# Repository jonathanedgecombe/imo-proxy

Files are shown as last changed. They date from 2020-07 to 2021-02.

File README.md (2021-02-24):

A hardware USB/HID proxy designed for the IntelliMouse Optical 1.1A. Overclocks to 1000Hz polling rate and adds switch debouncing.

Other mice could be supported by modifying the report descriptors & report parsing, or implementing a complete report descriptor parser.

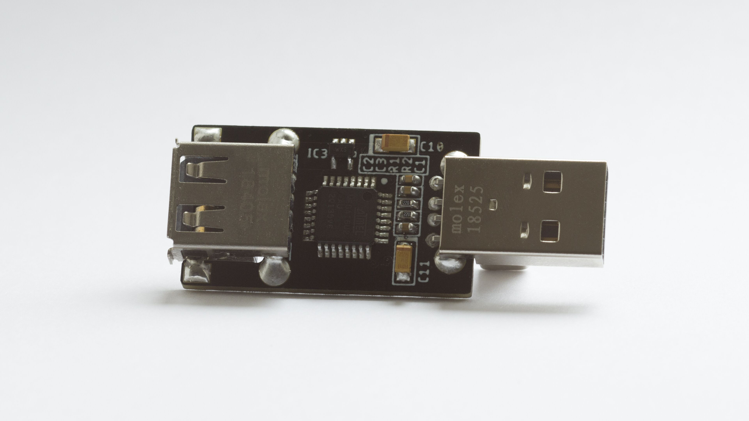
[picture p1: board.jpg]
Board photo


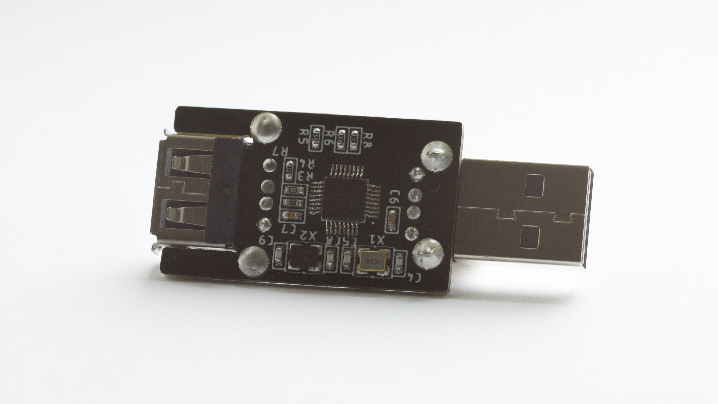
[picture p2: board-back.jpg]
Board photo back


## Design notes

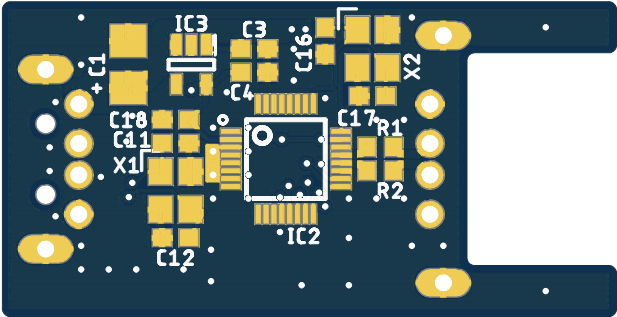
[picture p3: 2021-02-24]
render-back.png

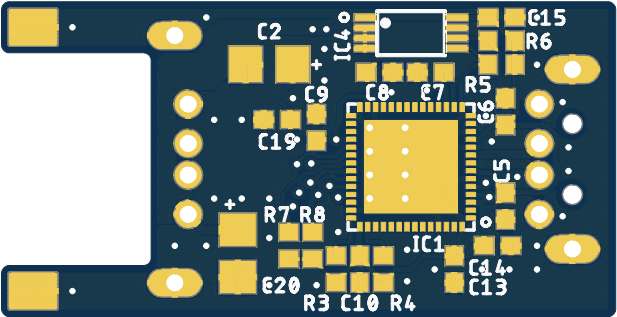
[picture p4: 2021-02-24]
render.png

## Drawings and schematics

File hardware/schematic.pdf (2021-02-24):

# GND 100nF 16MHz 12MHz

J1

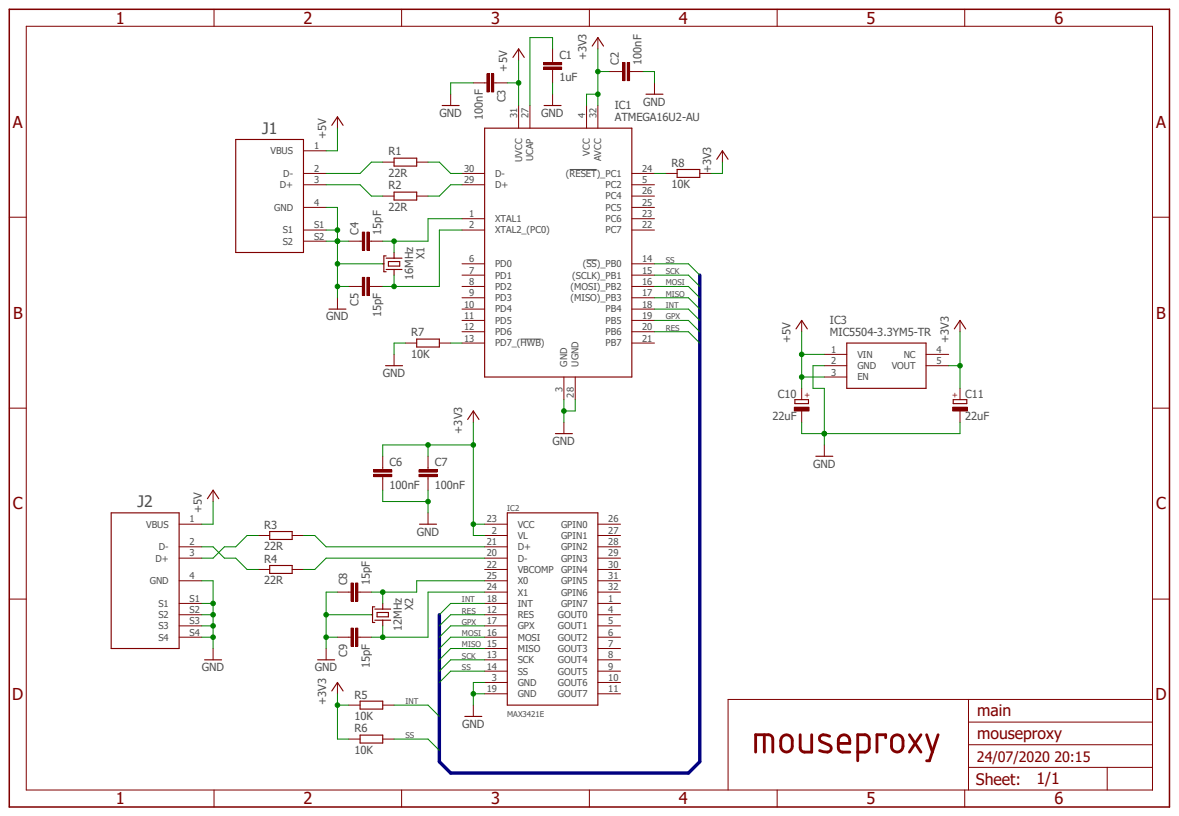
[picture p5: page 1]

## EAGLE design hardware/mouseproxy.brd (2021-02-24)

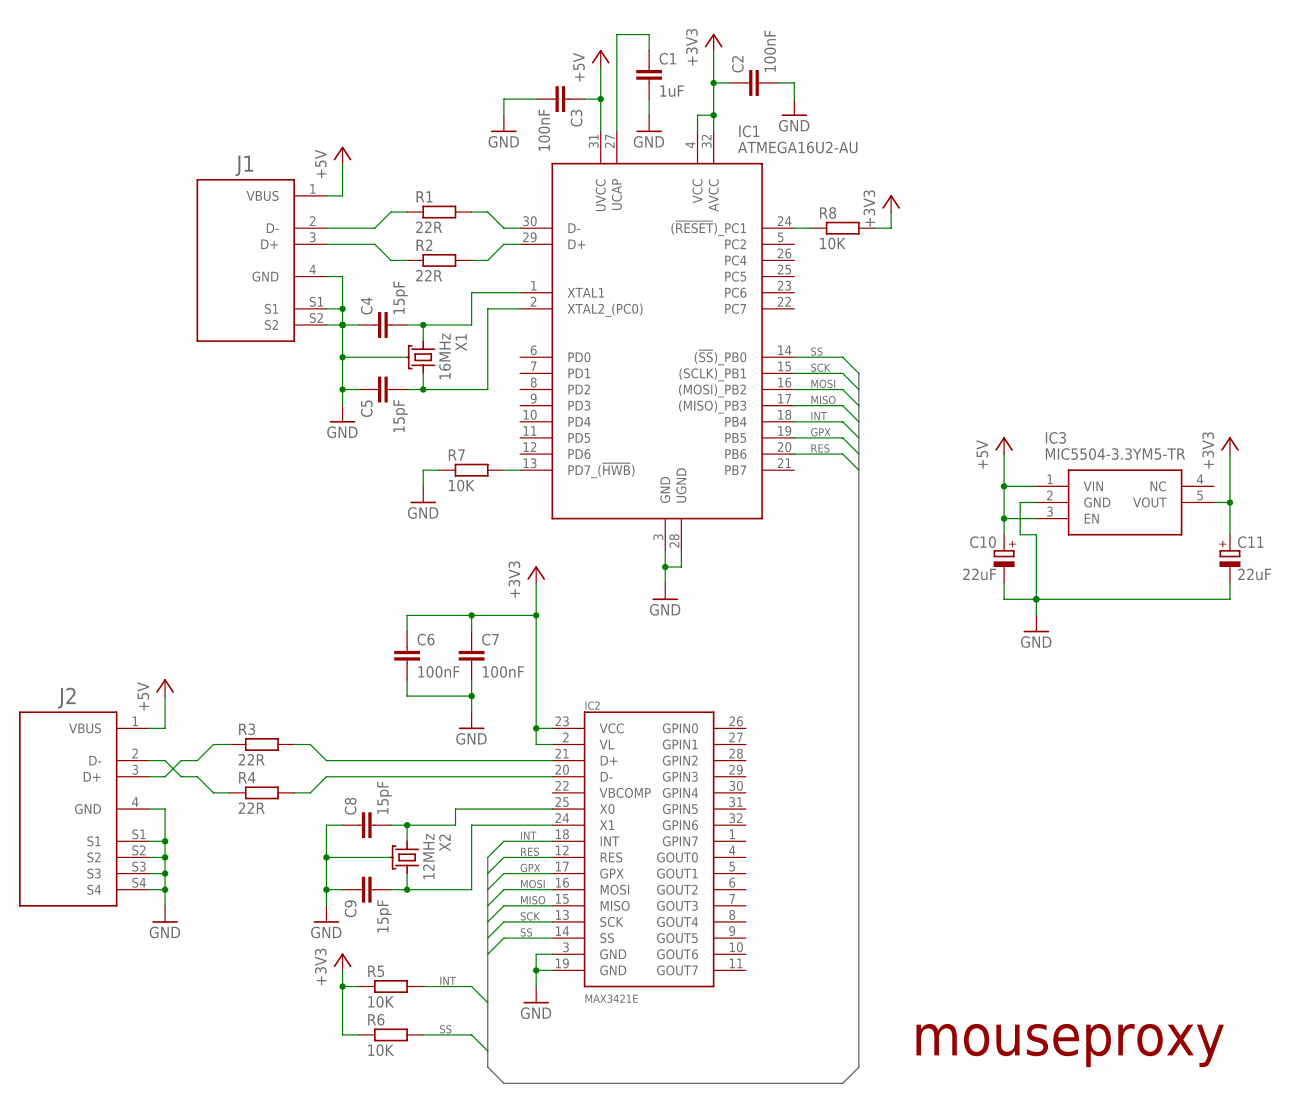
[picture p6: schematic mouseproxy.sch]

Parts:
C1: 1uF; 0603
C2, C3, C6, C7: 100nF; 0603
C4, C5, C8, C9: 15pF; 0603
C10, C11: 22uF; 1206POL
IC1: ATMEGA16U2-AU; QFP80P900X900X120-32N
IC2: MAX3421E; TQFP32-5MM
IC3: MIC5504-3.3YM5-TR; SOT95P280X130-5N
J1: 48037-0001
J2: 48258-0001
R1, R2, R3, R4: 22R; 0603
R5, R6, R7, R8: 10K; 0603
X1: 16MHz; 3.2X2.5_4
X2: 12MHz; 3.2X2.5_4

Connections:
+3V3: C2.1, C6.1, C7.1, C11.1 (+), IC1.4 (VCC), IC1.32 (AVCC), IC2.2 (VL), IC2.23 (VCC), IC3.5 (VOUT), R5.1, R6.1, R8.2
+5V: C3.1, C10.1 (+), IC1.31 (UVCC), IC3.1 (VIN), IC3.3 (EN), J1.1 (VBUS), J2.1 (VBUS)
D_F_N: IC1.30 (D-), R1.2
D_F_P: IC1.29 (D+), R2.2
D_N: J1.2 (D-), R1.1
D_P: J1.3 (D+), R2.1
GND: C1.2, C2.2, C3.2, C4.1, C5.1, C6.2, C7.2, C8.1, C9.1, C10.2 (-), C11.2 (-), IC1.3 (GND), IC1.28 (UGND), IC2.3 (GND), IC2.19 (GND), IC3.2 (GND), J1.4 (GND), J1.S1, J1.S2, J2.4 (GND), J2.S1, J2.S2, J2.S3, J2.S4, R7.1, X1.P$2 (GND), X1.P$4 (GND), X2.P$2 (GND), X2.P$4 (GND)
GPX: IC1.19 (PB5), IC2.17 (GPX)
HOST_D_N: J2.2 (D-), R4.1
HOST_D_P: J2.3 (D+), R3.1
HOST_F_D_N: IC2.20 (D-), R4.2
HOST_F_D_P: IC2.21 (D+), R3.2
INT: IC1.18 (PB4), IC2.18 (INT), R5.2
MISO: IC1.17 ((MISO)_PB3), IC2.15 (MISO)
MOSI: IC1.16 ((MOSI)_PB2), IC2.16 (MOSI)
unnamed: C5.2, IC1.2 (XTAL2_(PC0)), X1.P$3 (XT2)
unnamed: C4.2, IC1.1 (XTAL1), X1.P$1 (XT1)
unnamed: C1.1, IC1.27 (UCAP)
unnamed: C9.2, IC2.24 (X1), X2.P$3 (XT2)
unnamed: C8.2, IC2.25 (X0), X2.P$1 (XT1)
unnamed: IC1.13 (PD7_(!HWB!)), R7.2
unnamed: IC1.24 ((!RESET!)_PC1), R8.1
RES: IC1.20 (PB6), IC2.12 (RES)
SCK: IC1.15 ((SCLK)_PB1), IC2.13 (SCK)
SS: IC1.14 ((!SS!)_PB0), IC2.14 (SS), R6.2

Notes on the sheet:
mouseproxy

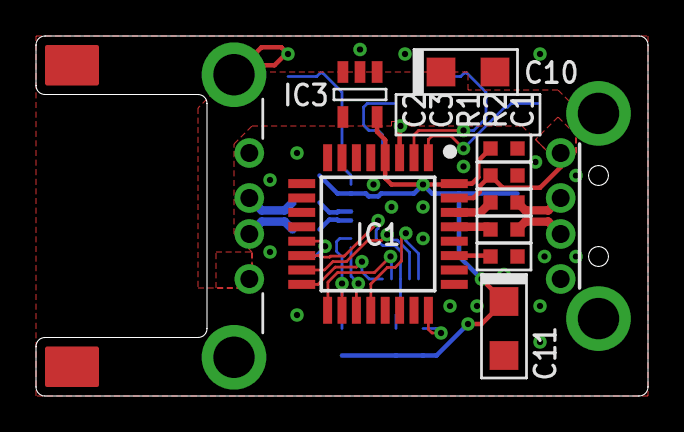
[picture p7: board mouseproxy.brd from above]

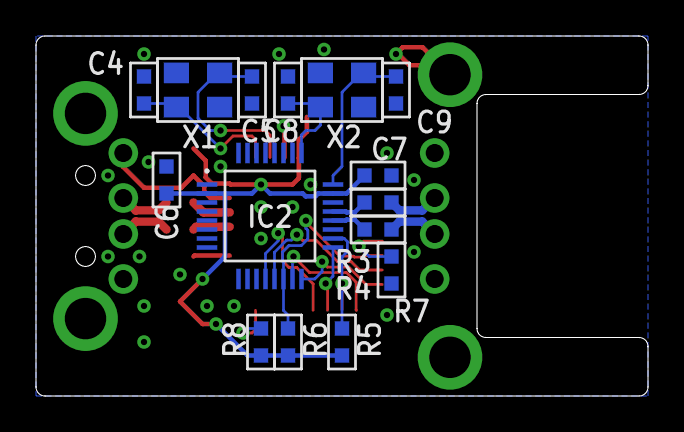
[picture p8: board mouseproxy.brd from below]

Board: 2 copper layers, 34.0 x 20.0 mm, 26 parts (15 on the bottom side), 25 nets.

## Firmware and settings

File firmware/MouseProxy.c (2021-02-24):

/*
Copyright 2020 Jonathan Edgecombe <jonathanedgecombe@gmail.com>

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
THE SOFTWARE IS PROVIDED "AS IS" AND THE AUTHOR DISCLAIMS ALL WARRANTIES
WITH REGARD TO THIS SOFTWARE INCLUDING ALL IMPLIED WARRANTIES OF
MERCHANTABILITY AND FITNESS. IN NO EVENT SHALL THE AUTHOR BE LIABLE FOR
ANY SPECIAL, DIRECT, INDIRECT, OR CONSEQUENTIAL DAMAGES OR ANY DAMAGES
WHATSOEVER RESULTING FROM LOSS OF USE, DATA OR PROFITS, WHETHER IN AN
ACTION OF CONTRACT, NEGLIGENCE OR OTHER TORTIOUS ACTION, ARISING OUT OF
OR IN CONNECTION WITH THE USE OR PERFORMANCE OF THIS SOFTWARE.
*/

#include "MouseProxy.h"

#include <string.h>
#include <stdint.h>
#include <stdbool.h>

#define bmBIT0 _BV(0)
#define bmBIT1 _BV(1)
#define bmBIT2 _BV(2)
#define bmBIT3 _BV(3)
#define bmBIT4 _BV(4)
#define bmBIT5 _BV(5)
#define bmBIT6 _BV(6)
#define bmBIT7 _BV(7)

#define rRCVFIFO      1

#define rSUDFIFO      4

#define rRCVBC        6

#define rUSBIRQ       13
#define bmOSCOKIRQ    bmBIT0

#define rUSBCTL       15
#define bmCHIPRES     bmBIT5

#define rCPUCTL       16
#define bmIE          bmBIT0

#define rPINCTL       17
#define bmFDUPSPI     bmBIT4
#define bmINTLEVEL    bmBIT3
#define bmPOSINT      bmBIT2
#define bmGPXB        bmBIT1
#define bmGPXA        bmBIT0

#define rREVISION     18

#define rHIRQ         25
#define bmHXFRDNIRQ   bmBIT7
#define bmFRAMEIRQ    bmBIT6
#define bmCONDETIRQ   bmBIT5
#define bmRCVDAVIRQ   bmBIT2
#define bmBUSEVENTIRQ bmBIT0

#define rHIEN         26
#define bmFRAMEIE     bmBIT6
#define bmCONDETIE    bmBIT5

#define rMODE         27
#define bmDPPULLDN    bmBIT7
#define bmDMPULLDN    bmBIT6
#define bmDELAYISO    bmBIT5
#define bmSEPIRQ      bmBIT4
#define bmSOFKAENAB   bmBIT3
#define bmHUBPRE      bmBIT2
#define bmLOWSPEED    bmBIT1
#define bmHOST        bmBIT0

#define rPERADDR      28

#define rHCTL         29
#define bmRCVTOG1     bmBIT5
#define bmRCVTOG0     bmBIT4
#define bmSAMPLEBUS   bmBIT2
#define bmBUSRST      bmBIT0

#define rHXFR         30

#define rHRSL         31
#define bmJSTATUS     bmBIT7
#define bmKSTATUS     bmBIT6

#define MODE_FS_HOST (bmDPPULLDN | bmDMPULLDN | bmHOST | bmSEPIRQ)
#define MODE_LS_HOST (bmDPPULLDN | bmDMPULLDN | bmHOST | bmSEPIRQ | bmLOWSPEED)

#define STATE_RESET          0
#define STATE_RESET_WAIT     1
#define STATE_MODE_SET       2
#define STATE_BUS_SAMPLE     3
#define STATE_BUS_RESET      4
#define STATE_BUS_RESET_WAIT 5
#define STATE_SOF_WAIT       6
#define STATE_GET_DESCRIPTOR 7
#define STATE_SET_ADDRESS    8
#define STATE_HID_START      9
#define STATE_DONE           10
#define STATE_ERROR          255

#define DEBOUNCE_TIME 20

#define SS   _BV(PB0)
#define SCK  _BV(PB1)
#define MOSI _BV(PB2)
#define MISO _BV(PB3)
#define RES  _BV(PB6)

static uint8_t PrevMouseHIDReportBuffer[sizeof(USB_MouseReport_Data_t)];

USB_ClassInfo_HID_Device_t Mouse_HID_Interface = {
		.Config =
			{
				.InterfaceNumber              = INTERFACE_ID_Mouse,
				.ReportINEndpoint             =
					{
						.Address              = MOUSE_EPADDR,
						.Size                 = MOUSE_EPSIZE,
						.Banks                = 1,
					},
				.PrevReportINBuffer           = PrevMouseHIDReportBuffer,
				.PrevReportINBufferSize       = sizeof(PrevMouseHIDReportBuffer),
			},
	};

volatile uint8_t state = STATE_RESET;
volatile uint8_t buttons = 0;
volatile uint8_t debounce[5] = {0, 0, 0, 0, 0};

int main(void) {
	MCUSR &= ~(1 << WDRF);
	wdt_disable();

	clock_prescale_set(clock_div_1);

	USB_Init();

	sei();

	DDRB |= SS | MOSI | SCK | RES;
	SPCR = _BV(SPE) | _BV(MSTR);
	SPSR = _BV(SPI2X);
	PORTB |= SS | RES;

	_delay_ms(10);
	PORTB &= RES;
	_delay_ms(10);
	PORTB |= RES;
	_delay_ms(10);

	while (true) {
		tick();
		HID_Device_USBTask(&Mouse_HID_Interface);
		USB_USBTask();
	}
}

bool CALLBACK_HID_Device_CreateHIDReport(USB_ClassInfo_HID_Device_t* const HIDInterfaceInfo, uint8_t* const ReportID, const uint8_t ReportType, void* ReportData, uint16_t* const ReportSize) {
	USB_MouseReport_Data_t* MouseReport = (USB_MouseReport_Data_t*) ReportData;

	bool got = false;

	if (state == STATE_DONE) {
		uint8_t flags = 0;

		reg_write(rHXFR, 0x00 | 0x01);

		for (uint8_t i = 0; i < 255; i++) {
			flags = fast_read();
			if (flags & bmHXFRDNIRQ) {
				reg_write(rHIRQ, bmHXFRDNIRQ);
				got = true;
				break;
			}
		}

		if (!got) {
			for (uint8_t i = 0; i < 50; i++) {
				flags = fast_read();
				if (flags & bmHXFRDNIRQ) {
					reg_write(rHIRQ, bmHXFRDNIRQ);
					got = true;
					break;
				}

				if (i >= 38) {
					_delay_ms(1);
					} else {
					_delay_us(10);
				}
			}
		}

		if (got) {
			if (flags & bmRCVDAVIRQ) {
				uint8_t buffer[4];
				reg_read_buf(rRCVFIFO, 4, (uint8_t*) &buffer);
				reg_write(rHIRQ, bmRCVDAVIRQ);

				buttons = buffer[0];

				MouseReport->X = buffer[1];
				MouseReport->Y = buffer[2];
				MouseReport->Wheel = buffer[3];
			}
		}
	}

	for (uint8_t i = 0; i < 5; i++) {
		bool pressed = (buttons >> i) & 0x01;

		if (pressed || debounce[i] > 0) {
			if (pressed) {
				debounce[i] = DEBOUNCE_TIME;
				} else {
				debounce[i]--;
			}

			MouseReport->Button |= 1 << i;
		}
	}

	*ReportSize = sizeof(USB_MouseReport_Data_t);
	return false;
}

void tick() {
	switch (state) {
		case STATE_RESET:
			reg_write(rUSBCTL, bmCHIPRES);
			reg_write(rUSBCTL, 0);
			_delay_ms(10);
			state = STATE_RESET_WAIT;
			return;

		case STATE_RESET_WAIT:
			if (reg_read(rUSBIRQ) & bmOSCOKIRQ) {
				state = STATE_MODE_SET;
			} else {
				_delay_ms(1);
			}
			return;

		case STATE_MODE_SET:
			reg_write(rPINCTL, bmFDUPSPI | bmINTLEVEL | bmGPXB);
			reg_write(rHIEN, bmCONDETIE | bmFRAMEIE);
			reg_write(rMODE, MODE_LS_HOST);
			_delay_ms(1);
			state = STATE_BUS_SAMPLE;
			return;

		case STATE_BUS_SAMPLE:
			reg_write(rHCTL, bmSAMPLEBUS);
			_delay_ms(1);
			uint8_t sample = reg_read(rHRSL);
			if (sample & bmJSTATUS) {
				if (sample & bmKSTATUS) {
					state = STATE_ERROR;
				} else {
					if (reg_read(rMODE) & bmLOWSPEED) {
						reg_write(rMODE, MODE_LS_HOST);
					} else {
						reg_write(rMODE, MODE_FS_HOST);
					}

					reg_write(rHIRQ, bmCONDETIRQ);
					state = STATE_BUS_RESET;
				}
			} else {
				if (sample & bmKSTATUS) {
					if (reg_read(rMODE) & bmLOWSPEED) {
						reg_write(rMODE, MODE_FS_HOST);
					} else {
						reg_write(rMODE, MODE_LS_HOST);
					}

					reg_write(rHIRQ, bmCONDETIRQ);
					state = STATE_BUS_RESET;
				} else {
					// SE0 state
				}
			}

			_delay_ms(1);
			return;

		case STATE_BUS_RESET:
			reg_write(rCPUCTL, bmIE);
			reg_write(rHIRQ, bmBUSEVENTIRQ);
			reg_write(rHCTL, bmBUSRST);
			_delay_ms(1);
			state = STATE_BUS_RESET_WAIT;
			return;

		case STATE_BUS_RESET_WAIT:
			if ((reg_read(rHCTL) & bmBUSRST) == 0) {
				state = STATE_SOF_WAIT;
				reg_write(rHIRQ, bmBUSEVENTIRQ);
				reg_write(rMODE, reg_read(rMODE) | bmSOFKAENAB);
			} else {
				_delay_ms(1);
			}
			return;

		case STATE_SOF_WAIT:
			if (reg_read(rHIRQ) & bmFRAMEIRQ) {
				state = STATE_GET_DESCRIPTOR;
			} else {
				_delay_us(25);
			}
			return;

		case STATE_GET_DESCRIPTOR:
			reg_write(rPERADDR, 0);
			if (setup(0x80, 0x06, 0x00, 0x01, 0x00, 0x00, 0x08, 0x00)) {
				uint8_t descBuffer[8];
				if (bulk_in(0, 8, (uint8_t*) &descBuffer)) {
					if (hs_out()) {
						state =STATE_SET_ADDRESS;
					}
				}
			}
			return;

		case STATE_SET_ADDRESS:
			if (setup(0x00, 0x05, 0x01, 0x00, 0x00, 0x00, 0x00, 0x00)) {
				if (hs_in()) {
					state = STATE_HID_START;
				}
			}
			return;

		case STATE_HID_START:
			reg_write(rPERADDR, 1);
			if (setup(0x00, 0x09, 0x01, 0x00, 0x00, 0x00, 0x00, 0x00)) {
				if (hs_in()) {
					state = STATE_DONE;
				}
			}
			return;

		case STATE_ERROR:
			// TODO error state
			return;
	}
}

bool setup(uint8_t type, uint8_t request, uint8_t valueL, uint8_t valueH, uint8_t indexL, uint8_t indexH, uint8_t lengthL, uint8_t lengthH) {
	uint8_t buffer[8] = {type, request, valueL, valueH, indexL, indexH, lengthL, lengthH};
	reg_write_buf(rSUDFIFO, 8, (uint8_t*) &buffer);
	reg_write(rHXFR, 0x10);

	for (uint8_t i = 0; i < 50; i++) {
		if (reg_read(rHIRQ) & bmHXFRDNIRQ) {
			reg_write(rHIRQ, bmHXFRDNIRQ);

			if ((reg_read(rHRSL) & 0x0F) == 0) {
				return true;
			} else {
				return false;
			}
		}

		_delay_us(250);
	}

	return false;
}

bool bulk_in(uint8_t ep, uint8_t length, uint8_t* buffer) {
	reg_write(rHCTL, bmRCVTOG1);
	reg_write(rHXFR, 0x00 | ep);
	
	for (uint8_t i = 0; i < 50; i++) {
		if (reg_read(rHIRQ) & bmHXFRDNIRQ) {
			reg_write(rHIRQ, bmHXFRDNIRQ);

			if ((reg_read(rHRSL) & 0x0F) == 0) {
				return transfer_in(length, buffer);
				} else {
				return false;
			}
		}

		_delay_us(250);
	}

	return false;
}

bool transfer_in(uint8_t length, uint8_t* buffer) {
	if (!(reg_read(rHIRQ) & bmRCVDAVIRQ)) {
		return false;
	}

	uint8_t rcv = reg_read(rRCVBC);
	if (rcv > length) rcv = length;

	reg_read_buf(rRCVFIFO, rcv, buffer);

	reg_write(rHIRQ, bmRCVDAVIRQ);

	return true;
}

bool hs_out() {
	return hs(0xA0);
}

bool hs_in() {
	return hs(0x80);
}

bool hs(uint8_t type) {
	reg_write(rHXFR, type);

	for (uint8_t i = 0; i < 50; i++) {
		if (reg_read(rHIRQ) & bmHXFRDNIRQ) {
			reg_write(rHIRQ, bmHXFRDNIRQ);

			if ((reg_read(rHRSL) & 0x0F) == 0) {
				return true;
				} else {
				return false;
			}
		}

		_delay_us(250);
	}

	return false;
}

void reg_write(uint8_t reg, uint8_t val) {
	PORTB &= ~SS;
	spi_write((reg << 3) | 0x02);
	spi_write(val);
	PORTB |= SS;
}

void reg_write_buf(uint8_t reg, uint8_t len, uint8_t* data) {
	PORTB &= ~SS;
	spi_write((reg << 3) | 0x02);
	for (uint8_t i = 0; i < len; i++) {
		spi_write(*data);
		data++;
	}
	PORTB |= SS;
}

uint8_t fast_read() {
	PORTB &= ~SS;
	uint8_t val = spi_read();
	PORTB |= SS;
	return val;
}

uint8_t reg_read(uint8_t reg) {
	PORTB &= ~SS;
	spi_write(reg << 3);
	uint8_t val = spi_read();
	PORTB |= SS;
	return val;
}

void reg_read_buf(uint8_t reg, uint8_t len, uint8_t* data) {
	PORTB &= ~SS;
	spi_write(reg << 3);
	for (uint8_t i = 0; i < len; i++) {
		*data = spi_read();
		data++;
	}
	PORTB |= SS;
}

void spi_write(uint8_t v) {
	SPDR = v;
	asm volatile("nop");
	while (!(SPSR & (1 << SPIF)));
}

uint8_t spi_read() {
	SPDR = 0;
	asm volatile("nop");
	while (!(SPSR & (1 << SPIF)));
	return SPDR;
}

void EVENT_USB_Device_ConfigurationChanged(void) {
	HID_Device_ConfigureEndpoints(&Mouse_HID_Interface);
	USB_Device_EnableSOFEvents();
}

void EVENT_USB_Device_ControlRequest(void) {
	HID_Device_ProcessControlRequest(&Mouse_HID_Interface);
}

void EVENT_USB_Device_StartOfFrame(void) {
	HID_Device_MillisecondElapsed(&Mouse_HID_Interface);
}

void CALLBACK_HID_Device_ProcessHIDReport(USB_ClassInfo_HID_Device_t* const HIDInterfaceInfo, const uint8_t ReportID, const uint8_t ReportType, const void* ReportData, const uint16_t ReportSize) {
	// Do nothing
}

void EVENT_USB_Device_Connect(void) {
	// Do nothing
}

void EVENT_USB_Device_Disconnect(void) {
	// Do nothing
}

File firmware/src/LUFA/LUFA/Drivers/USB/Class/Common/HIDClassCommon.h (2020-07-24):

/*
             LUFA Library
     Copyright (C) Dean Camera, 2017.

  dean [at] fourwalledcubicle [dot] com
           www.lufa-lib.org
*/

/*
  Copyright 2017  Dean Camera (dean [at] fourwalledcubicle [dot] com)

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
  The author disclaims all warranties with regard to this
  software, including all implied warranties of merchantability
  and fitness.  In no event shall the author be liable for any
  special, indirect or consequential damages or any damages
  whatsoever resulting from loss of use, data or profits, whether
  in an action of contract, negligence or other tortious action,
  arising out of or in connection with the use or performance of
  this software.
*/

/** \file
 *  \brief Common definitions and declarations for the library USB HID Class driver.
 *
 *  Common definitions and declarations for the library USB HID Class driver.
 *
 *  \note This file should not be included directly. It is automatically included as needed by the USB module driver
 *        dispatch header located in LUFA/Drivers/USB.h.
 */

/** \ingroup Group_USBClassHID
 *  \defgroup Group_USBClassHIDCommon  Common Class Definitions
 *
 *  \section Sec_USBClassHIDCommon_ModDescription Module Description
 *  Constants, Types and Enum definitions that are common to both Device and Host modes for the USB
 *  HID Class.
 *
 *  @{
 */

#ifndef _HID_CLASS_COMMON_H_
#define _HID_CLASS_COMMON_H_

	/* Includes: */
		#include "../../Core/StdDescriptors.h"
		#include "HIDParser.h"

	/* Enable C linkage for C++ Compilers: */
		#if defined(__cplusplus)
			extern "C" {
		#endif

	/* Preprocessor Checks: */
		#if !defined(__INCLUDE_FROM_HID_DRIVER)
			#error Do not include this file directly. Include LUFA/Drivers/USB.h instead.
		#endif

	/* Macros: */
		/** \name Keyboard Standard Report Modifier Masks */
		//@{
		/** Constant for a keyboard report modifier byte, indicating that the keyboard's left control key is currently pressed. */
		#define HID_KEYBOARD_MODIFIER_LEFTCTRL                    (1 << 0)

		/** Constant for a keyboard report modifier byte, indicating that the keyboard's left shift key is currently pressed. */
		#define HID_KEYBOARD_MODIFIER_LEFTSHIFT                   (1 << 1)

		/** Constant for a keyboard report modifier byte, indicating that the keyboard's left alt key is currently pressed. */
		#define HID_KEYBOARD_MODIFIER_LEFTALT                     (1 << 2)

		/** Constant for a keyboard report modifier byte, indicating that the keyboard's left GUI key is currently pressed. */
		#define HID_KEYBOARD_MODIFIER_LEFTGUI                     (1 << 3)

		/** Constant for a keyboard report modifier byte, indicating that the keyboard's right control key is currently pressed. */
		#define HID_KEYBOARD_MODIFIER_RIGHTCTRL                   (1 << 4)

		/** Constant for a keyboard report modifier byte, indicating that the keyboard's right shift key is currently pressed. */
		#define HID_KEYBOARD_MODIFIER_RIGHTSHIFT                  (1 << 5)

		/** Constant for a keyboard report modifier byte, indicating that the keyboard's right alt key is currently pressed. */
		#define HID_KEYBOARD_MODIFIER_RIGHTALT                    (1 << 6)

		/** Constant for a keyboard report modifier byte, indicating that the keyboard's right GUI key is currently pressed. */
		#define HID_KEYBOARD_MODIFIER_RIGHTGUI                    (1 << 7)
		//@}

		/** \name Keyboard Standard Report LED Masks */
		//@{
		/** Constant for a keyboard output report LED byte, indicating that the host's NUM LOCK mode is currently set. */
		#define HID_KEYBOARD_LED_NUMLOCK                          (1 << 0)

		/** Constant for a keyboard output report LED byte, indicating that the host's CAPS LOCK mode is currently set. */
		#define HID_KEYBOARD_LED_CAPSLOCK                         (1 << 1)

		/** Constant for a keyboard output report LED byte, indicating that the host's SCROLL LOCK mode is currently set. */
		#define HID_KEYBOARD_LED_SCROLLLOCK                       (1 << 2)

		/** Constant for a keyboard output report LED byte, indicating that the host's COMPOSE mode is currently set. */
		#define HID_KEYBOARD_LED_COMPOSE                          (1 << 3)

		/** Constant for a keyboard output report LED byte, indicating that the host's KANA mode is currently set. */
		#define HID_KEYBOARD_LED_KANA                             (1 << 4)
		//@}
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

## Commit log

2021-02-24 Add PCB
    [mouseproxy.brd, mouseproxy.sch]
2021-02-24 Add board photos and renders
